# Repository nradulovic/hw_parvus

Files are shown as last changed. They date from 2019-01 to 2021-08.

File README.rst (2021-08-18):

.. contents:: Table of Contents
   :depth: 3

Introduction
============

This document shall describe rationales used to design and build audio
power amplifier using TDA7293 integrated circuit.

Architecture
============

The amplifier architecture consists of the following sections:

The amplifier consists of the following section:
 - Amplifier (AMP) board (left and right channels)
 - Input/output filtering and Interface (IOI) board
 - Power supply and control (PSC) board
 
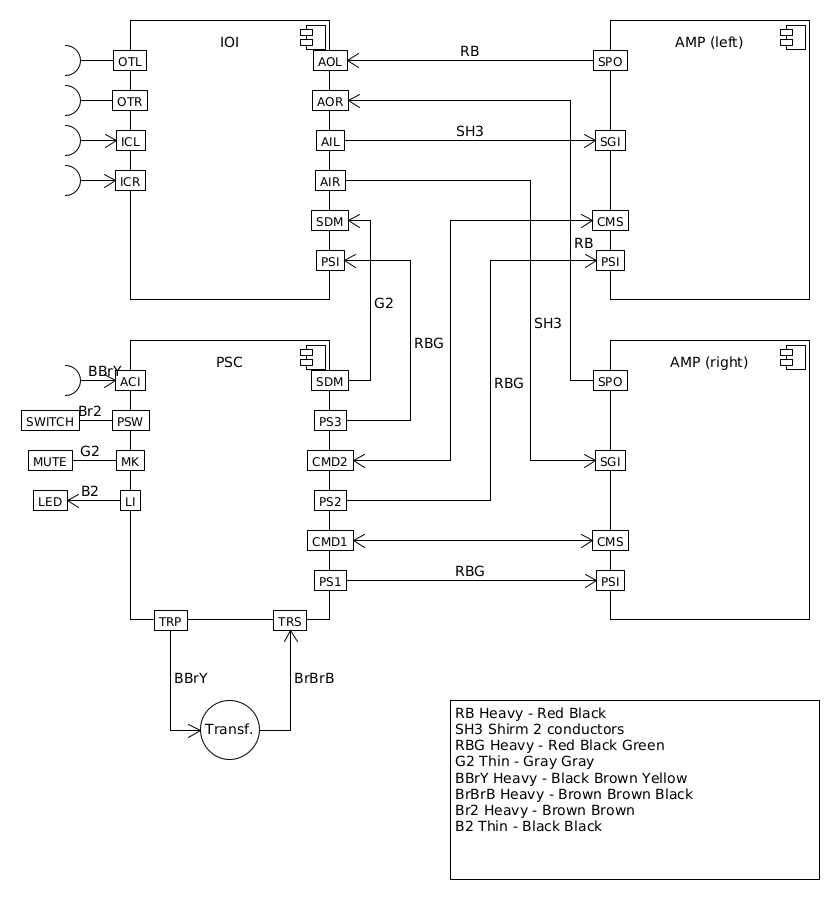
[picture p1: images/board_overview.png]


Each of these sections are implemented as a separate board.

Amplifier (AMP) board
=====================

Connections
-----------

The board features the following conntectors:

 - Power Supply Input - PSI: Vcc, GND, Vee
 - Speaker Output - SPO: Out, GND
 - Signal Input - SGI: In, SGND
 - Control and Mute Slave - CMS: Power sense, Mute, Clip, GND

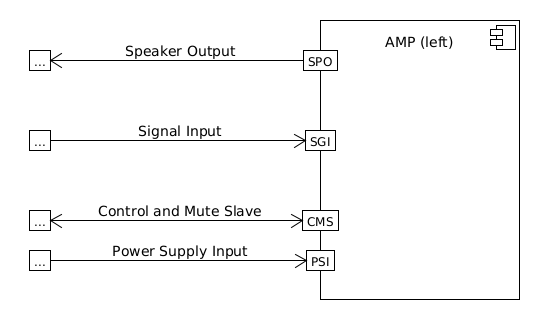
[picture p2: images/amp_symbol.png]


3D Render with components
-------------------------

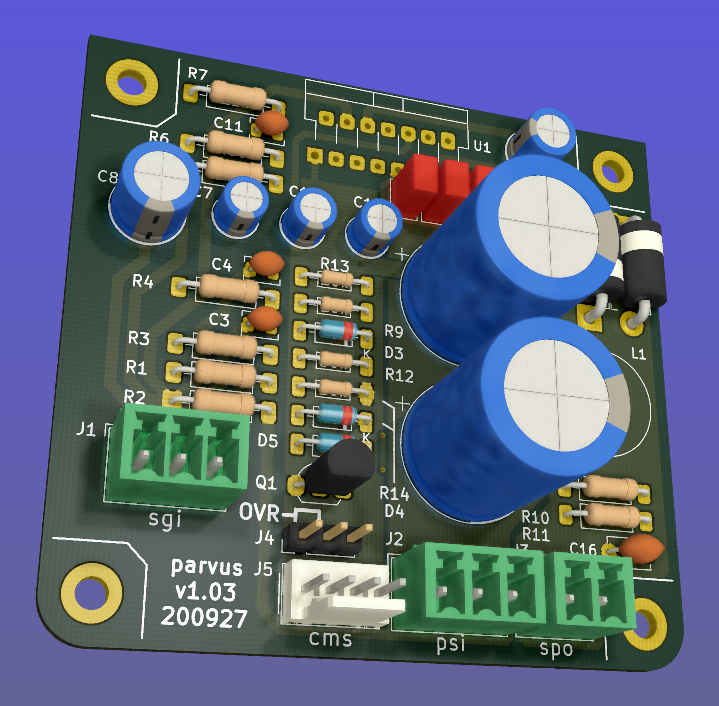
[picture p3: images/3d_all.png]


3D Render of board top layer
----------------------------

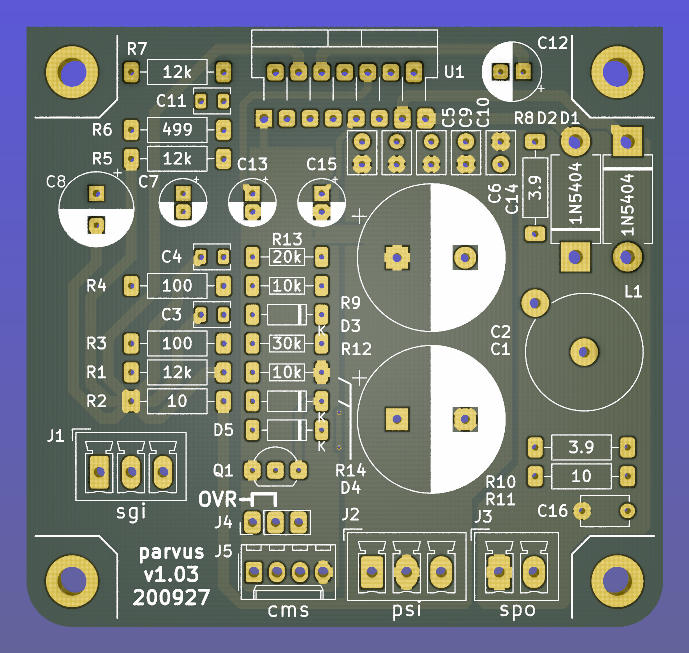
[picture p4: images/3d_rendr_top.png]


3D Render of board bottom layer
-------------------------------

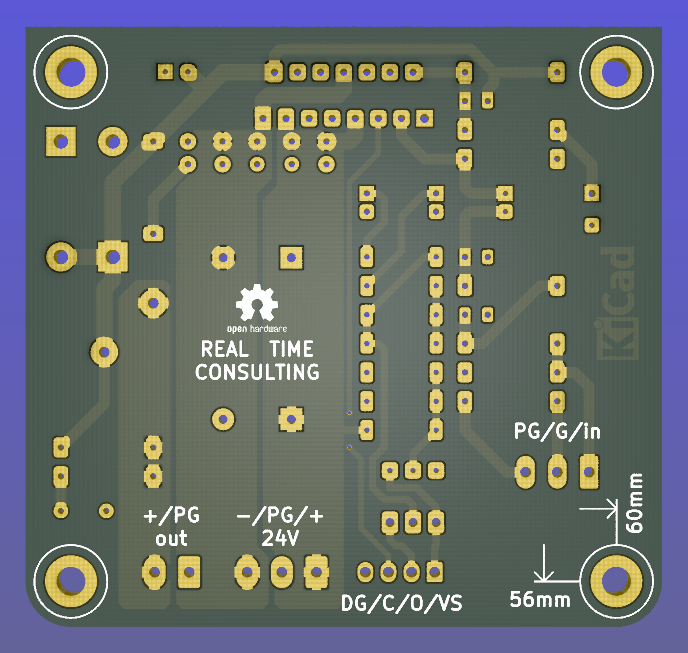
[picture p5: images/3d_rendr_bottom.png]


PCB Silkscreen plan
-------------------

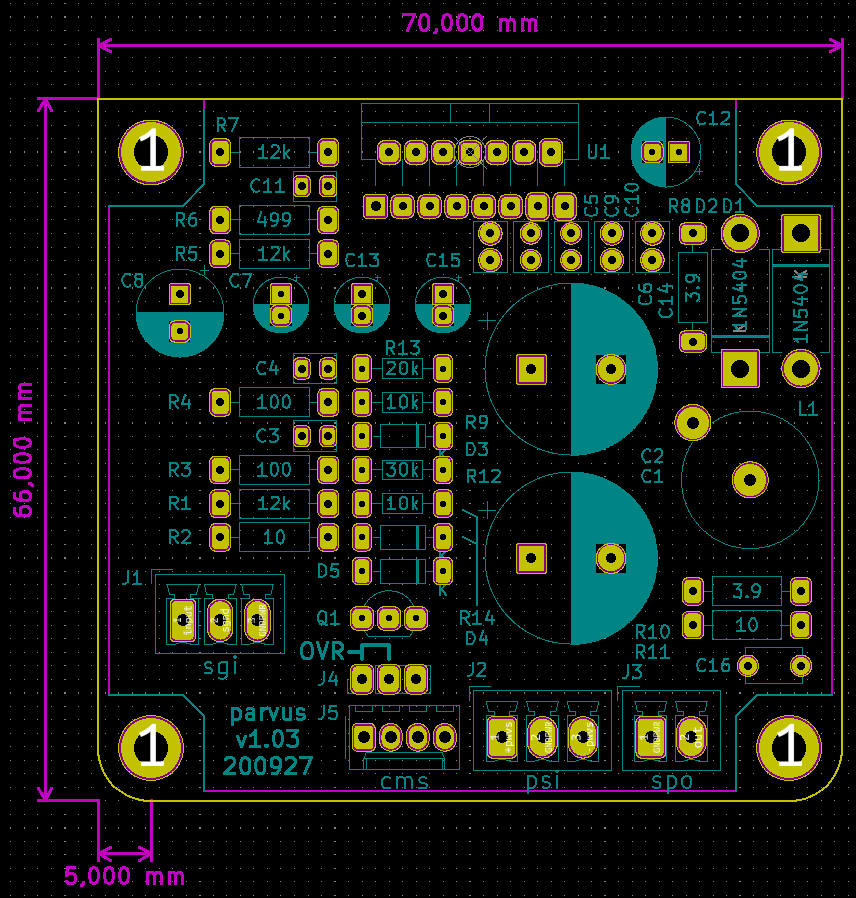
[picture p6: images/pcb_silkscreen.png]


Schematic
---------

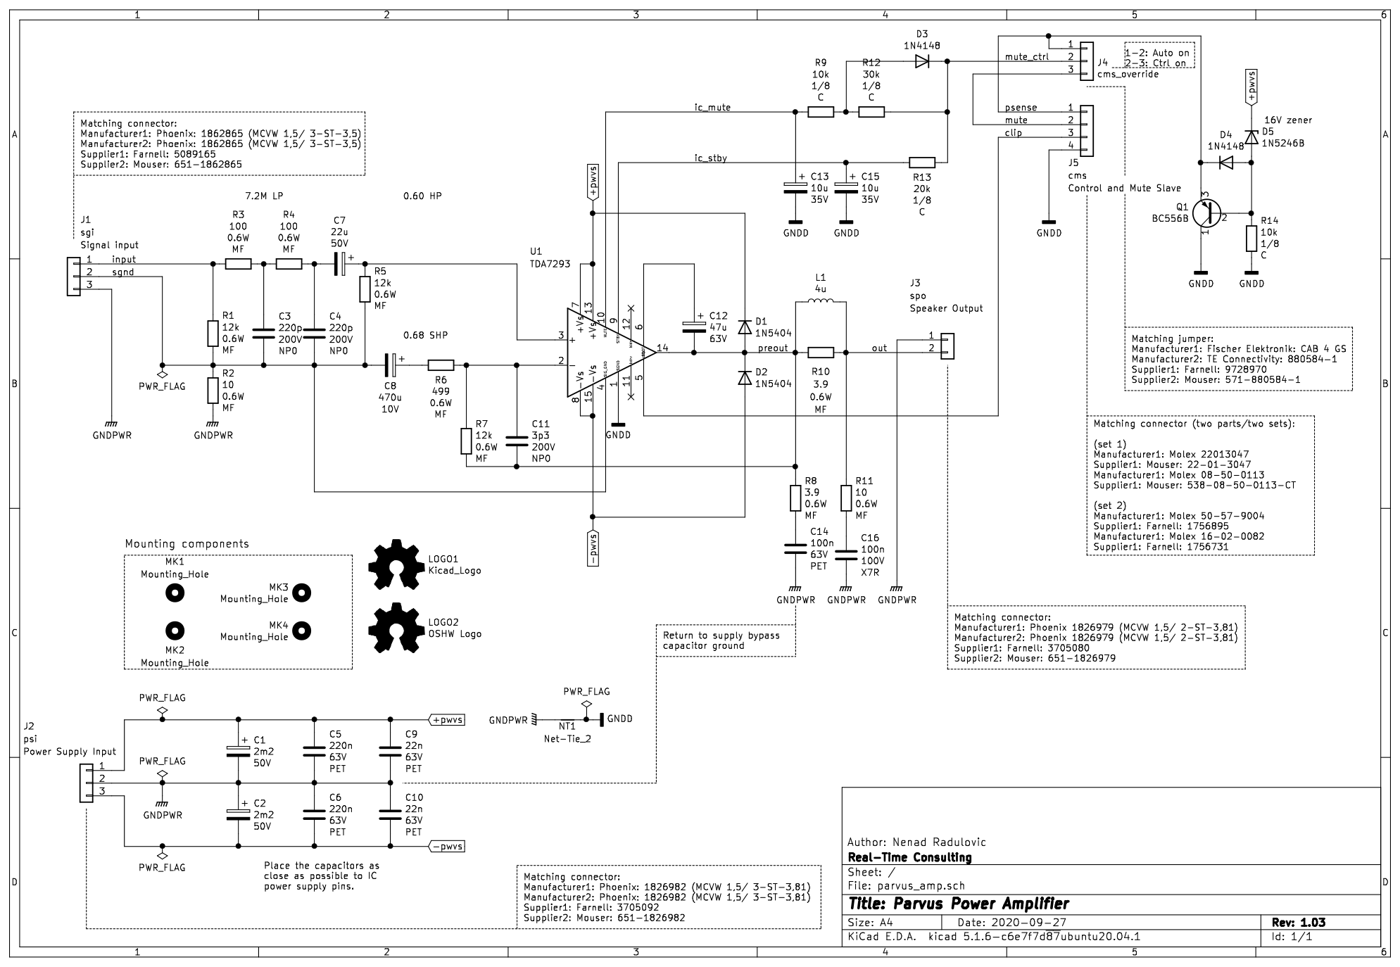
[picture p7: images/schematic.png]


Input low-pass filter
---------------------

For input filter we choose the frequency between 300kHz and 400kHz::

        +---+ Rlp1    +---+ Rlp2
    0---+   +----+----+   +---+---o Toward Amplifier IC block
        +---+    |    +---+   |
               ----- Clp1   ----- Clp2
               -----        -----
                 |            |
                === Ground   === Ground

Using the 2nd order CR low-pass filter calculator at URL:
*http://sim.okawa-denshi.jp/en/CRCRtool.php* we arrive at:

.. math::

    Rlp1 = 100 Ohm, Rlp2 = 100 Ohm

    Clp1 = 220pF,   Clp2 = 2.2nF

    fp1 = 352kHz

    fp2 = 14MHz

For more details please refer to: http://www.johnhearfield.com/RC/RC4.htm

The ground loop breaker resistor
--------------------------------

A ground loop breaker resistor is located between SGND and GNDPWR grounds. The
value of this resistor should be around 10 ohms.

Gain value
----------

Using inverted topology since we want to reduce common mode distortion in the
input stage. But in case of TDA7293 IC it is not easy to use inverted topology
since the mute circuit is implemented on positive OPAMP input.

The equivalent gain circuit resistance needs to stay below 600ohms. This is so
because all noise measurements in data-sheet were done with 600ohms or 0ohms.

Using low feedback gain is preferred for several reasons:
 * there is more loop gain available to reduce the distortion
 * reduced outout noues
 * lower offset at output

Nominal gain of an non-inverting amplifier is:

.. math::

    G=Rf/Rg+1

Since we have a voltage divider with same resistors in the front of the 
amplifier the total gain becomes:

.. math::

    G=Rf/Rg

The minimum gain specified in the TDA7293 datasheet is 26dB or 20 times. Just
to be on the safe side we choose 10% bigger value: 22

Chosen values for E24 series:
 * Rf = 12kOhm
 * Rg = 510 Ohm

Chosen values for E48 series:
 * Rf = 11kOhm
 * Rg = 499 Ohm

Frequency compensation
----------------------

The TDA7293 data-sheet does not provide enough of relevant data in order to
model the IC in AC domain. Since we can't model it there are no optimizations
available for the negative feedback circuit. But we can safely assume that
there are high frequency poles present in the TDA7293 transfer function. For
this reason we will add a few ``pF`` to calculated lead compensation
capacitor below (see ``Cadd``).

Lead compensation
^^^^^^^^^^^^^^^^^

Equivalent feedback network with lead compensation circuit::

          o Vout
          |
          *------+
          |      |
         +-+ Rf  |
         | |   ----- Cf=Cl (+Csi, see Input pin capacitance compensation)
         | |   -----
         +-+     |
   Vf     |      |
    o-----*------+
          |
         +-+ Rg
         | |
         | |
         +-+
          |
          o Input

Resistors `Rf` and `Rg` are part of feedback network. Capacitor `Cf` is the
compensation capacitor. The transfer function of this network is given as:

.. math::

    Vf(s)=I(s)*Rg

    Vout(s)=I(s)*(Rf||Cl + Rg)=I(s)*(Rf/(1+s*Rf*Cl)+Rg)

    H(s)=Vf(s)/Vout(s)=(Rg/(Rf+Rg))*((1+s*Rf*Cl)/(1+s*Re*Cl))

Zero:

.. math::

    wz=1/(Rf*Cl)

Pole:

.. math::

    wp=1/(Re*Cl)

Where:

.. math::

    Re=Rf||Rg=Rf*Rg/(Rf+Rg)

Rough estimation is to put additional 1-3pF in parallel to ``Rf``.

.. math::

	Cadd = 3pF

Input pin capacitance compensation
``````````````````````````````````

Input pins have the following parasitic capacitances associated:

* Cdiff
* Cm
* Cstray

The TDA7293 data-sheet does not specify any parameter regarding parasitic
input capacitances. Voltage feedback OPAMPS usually have both differential and
common-mode input impedances specified. In the absence of any information, it
is safe to use the model given in the next figure::

                   +----+ Zdiff
    +input o---+---|    |---+---o -input
               |   +----+   |
               |            |
              +-+ Zcm1     +-+ Zcm2
              | |          | |
              | |          | |
              +-+          +-+
               |            |
              ===          ===

We can use a rough estimation of values based on experience on using other 
audio FET OPAMPS, and typical values are around ``Cdiff=5pF``, ``Cm=4pF`` 
and ``Cstray=3pF``. All three equivalent capacitors are tied in parallel, 
so the total input capacitance becomes:

.. math::

    Cinput = Cdiff+Cm+Cstray=5pF+4pF+3pF=12pF

To mitigate this capacitance we can add capacitance `Csi` parallel to `Rf`
resistor. To compensate for this the following equation is applied:

.. math::

    Rf*Cf=Rg*Cinput

    Csi=Cinput*Rg/Rf=0.5pF

The final ``Cf`` value is:

.. math::

    Cf=Cl+Csi+Cadd=0+2+0.5=2.5pF

Any NP0 based capacitor around ``3pF`` will be good for this purpose.

Input/output filtering and Interface (IOI) board
================================================

Input circuit
-------------

Input EMI suppression
^^^^^^^^^^^^^^^^^^^^^

To protect the input from EMI we will use the following Zobel network::

          o Positive input or negative input
          |
          |
        ----- Czi
        -----
          |
          |
         +-+  Rzi
         | |
         | |
         +-+
          |
         === Ground

For most input cables characteristic impedance falls in range between
50 and 100ohm impedance and we are using the 75ohm as the middle value. The
resistor Rzi is ``Rzi=75ohm`` and the capacitor Czi is ``Czi=220pF``.
This network should be placed right at the input connector, not on the
main amplifier PCB.

Also, a 100n X7R capacitor shall be placed between SGND and chassis right at the
input connector. This capacitor will shunt radio and other interfirence signal
into the Chassis Ground potential.

Output circuit
--------------

Output EMI suppression
^^^^^^^^^^^^^^^^^^^^^^

Output network consists of upstream and downstream Zobel Network and of output
coil (``Ld``) with parallel, damping resistor (``Rd``). Upstream Zobel network 
provides a low-inductance load for the output stage at very high frequencies 
and allows high-frequency currents to circulate local to the output stage. The 
downstream Zobel network provides a good resistive termination right at the 
speaker terminals at high frequencies, helping to reduce RFI ingress and damp
resonances with, or reflections from, the speaker cables.
The output circuit is the following::

             Ld
             xxx
        +---x   x   x---+
        |        xxx    |
        |               |
        |   +-------+   |
    o---+---|       |---+---o
    Vout    +-------+   |   Vspeaker
        Rd              |
                      ----- Cz2 = 100nF
                      -----
                        |
                        |
                       +-+  Rz1 = 10 Ohm
                       | |
                       | |
                       +-+
                        |
                       ===

The output coil ``Ld`` provides high frequency isolation of output load from 
output stage in TDA7293. The inductance value should be between 2uH up to 5uH.
Output shunt resistor should be between 2 and 5 Ohms. See
*Douglas Self - Audio Power Amplifier Design Handbook, 3rd Ed., Output networks, chapter 7*
for effect on power amplifier transfer function.

Power supply
============

Power amplifier power supply
----------------------------

The power supply section is using single bank of 10mF capacitors.

We are using dual symmetrical supplies from since dual secondaries.

The main voltage supplies are supplied directly from reservoir capacitors. This
supply powers the high current, high power output sections of TDA7293.

Before rectifier diodes a snubber RC circuit should be placed to decrease diode
switching impulse. Recommended values are ``Rsn = 1 Ohm``, ``Csn = 470nF``::

          o Vsupply
          |
          |
        ----- Csn = 470nF
        -----
          |
          |
         +-+  Rsn = 1 Ohm
         | |
         | |
         +-+
          |
         === Ground

This snubber may be placed near the IC power supply lines, too.

AC mains
--------

NOTE:
 * On case chassis there should be a safety ground screw just near at the input
   220V socket.

Chassis
=======

Component height
----------------

Power supply capacitors on amplifier boards:

* 30mm (10mF)

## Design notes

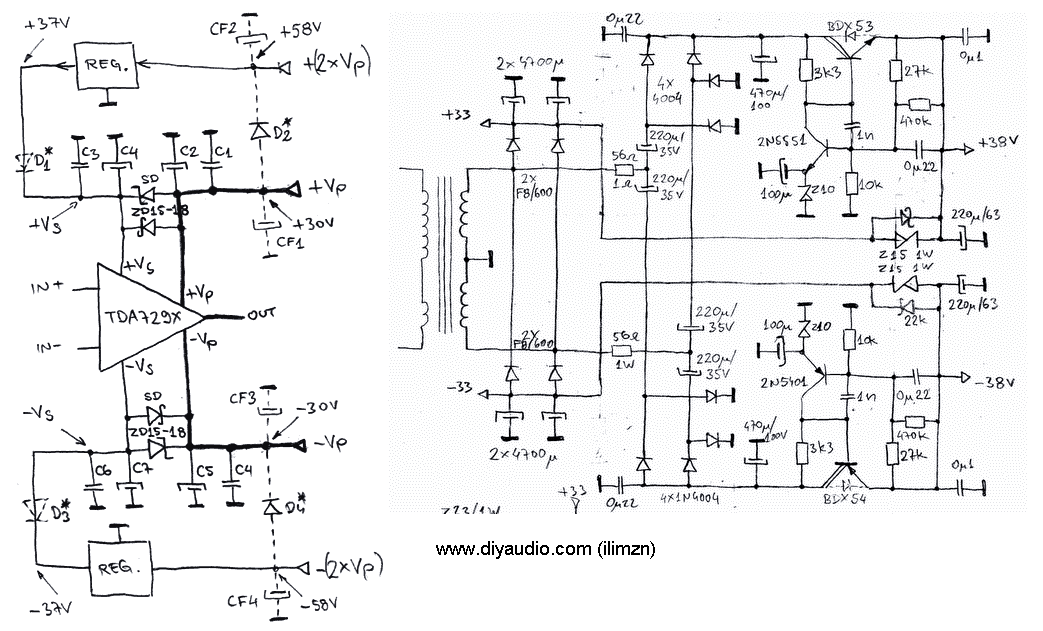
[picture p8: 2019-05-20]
docs/TDA7294_ilimzn.PNG

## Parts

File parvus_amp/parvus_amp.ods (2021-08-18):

Reference | Quantity | Value | Footprint | Datasheet | Manufacturer1 | Manufacturer2 | Supplier1 | Supplier2 | Type | Voltage | Power
C1 C2 | 2 | 2m2 | Capacitor_THT:CP_Radial_D16.0mm_P7.50mm | http://www.farnell.com/datasheets/2321616.pdf | Rybicon: 50YXJ2200M16X35.5 | Nichicon: UPW1V222MHD | Farnell: 2346272 | Mouser: 647-UPW1V222MHD |  | 50V
C11 | 1 | 3p3 | Capacitor_THT:C_Disc_D3.8mm_W2.6mm_P2.50mm | http://www.farnell.com/datasheets/2577345.pdf | Kemet: C315C339D2G5TA | Kemet: C315C339D2G5TA | Farnell: 2819636 | Mouser: 80-C315C339D2G | NP0 | 200V
C12 | 1 | 47u | Capacitor_THT:CP_Radial_D6.3mm_P2.50mm | http://www.farnell.com/datasheets/2321616.pdf | Rybicon: 63YXJ47M6.3X11 | Nichicon: UPW1H470MED | Farnell: 2346274 | Mouser: 647-UPW1H470MED |  | 63V
C13 C15 | 2 | 10u | Capacitor_THT:CP_Radial_D5.0mm_P2.00mm | http://www.farnell.com/datasheets/1723232.pdf | Multicomp: MCGPR35V106M5X11 | Nichicon: UVZ1V100MDD1TD | Farnell: 9451242 | Mouser: 647-UVZ1V100MDD1TD |  | 35V
C14 | 1 | 100n | Capacitor_THT:C_Rect_L4.6mm_W3.0mm_P2.50mm_MKS02_FKP02 | http://www.farnell.com/datasheets/1306005.pdf | WIMA: MKS0C031000C00KSSD | WIMA: MKS0C031000C00KSSD | Farnell: 1006004 | Mouser: 505-MKS02.1/63/10 | PET | 63V
C16 | 1 | 100n | Capacitor_THT:C_Disc_D5.1mm_W3.2mm_P5.00mm | http://www.farnell.com/datasheets/2095938.pdf | AVX: SR211C104KAR | AVX: SR211C104KAR | Farnell: 1100408 | Mouser: 581-SR211C104KAR | X7R | 100V
C3 C4 | 2 | 220p | Capacitor_THT:C_Disc_D3.8mm_W2.6mm_P2.50mm | http://www.farnell.com/datasheets/2577335.pdf | Kemet: C315C221K2G5TA | Kemet: C315C221K2G5TA | Farnell: 2819626 | Mouser: 80-C315C221K2G | NP0 | 200V
C5 C6 | 2 | 220n | Capacitor_THT:C_Rect_L4.6mm_W3.0mm_P2.50mm_MKS02_FKP02 | http://www.farnell.com/datasheets/1306005.pdf | WIMA: MKS0C032200C00KSSD | WIMA: MKS0C032200C00KSSD | Farnell: 1890123 | Mouser: 505-MKS0C032200C00KS | PET | 63V
C7 | 1 | 22u | Capacitor_THT:CP_Radial_D5.0mm_P2.00mm | http://www.farnell.com/datasheets/2328501.pdf | Rybicon: 50YXJ22MTA5X11 | Nichicon: UPW2A22MDD | Farnell: 2346268 | Mouser: 647-UPW2A22MDD |  | 50V
C8 | 1 | 470u | Capacitor_THT:CP_Radial_D8.0mm_P3.50mm | http://www.farnell.com/datasheets/2321616.pdf | Rybicon:10YXJ470M6.3X11 | Nichicon: UPW0J471MPD | Farnell: 2346252 | Mouser: 647-UPW0J471MPD |  | 10V
C10 C9 | 2 | 22n | Capacitor_THT:C_Rect_L4.6mm_W3.0mm_P2.50mm_MKS02_FKP02 | http://www.farnell.com/datasheets/1306005.pdf | WIMA: MKS0C022200B00KSSD | WIMA: MKS0C022200B00KSSD | Farnell: 1006001 | Mouser: 505-MKS02.022/63/10 | PET | 63V
D1 D2 | 2 | 1N5404 | Diode_THT:D_DO-201AD_P12.70mm_Horizontal | http://www.onsemi.com/PowerSolutions/supportDoc.do?type=models&rpn=1N5404 | ON Semiconductor: 1N5404RL | ON Semiconductor: 1N5404RL | Farnell: 9556141 | Mouser: 863-1N5404RLG
D3 D4 | 2 | 1N4148 | Diode_THT:D_DO-35_SOD27_P7.62mm_Horizontal | https://www.onsemi.com/pub/Collateral/1N914A-D.pdf | ON Semiconductor: 1N4148 | ON Semiconductor: 1N4148 | Farnell: 2322485 | Mouser: 512-1N4148
D5 | 1 | 1N5246B | Diode_THT:D_DO-35_SOD27_P7.62mm_Horizontal | https://www.onsemi.com/pub/Collateral/1N5221B-D.PDF | ON Semiconductor: 1N5246BTR | ON Semiconductor: 1N5246BTR | Farnell: 2453748 | Mouser: 512-1N5246BTR
J1 | 1 | input | Connector_Phoenix_MC:PhoenixContact_MCV_1,5_3-G-3.5_1x03_P3.50mm_Vertical | http://www.farnell.com/datasheets/2309782.pdf | Phoenix: 1843619 (MCV 1,5/ 3-G-3,50) | Phoenix: 1843619 (MCV 1,5/ 3-G-3,50) | Farnell: 3704828 | Mouser: 651-1843619
J2 | 1 | power | Connector_Phoenix_MC:PhoenixContact_MCV_1,5_3-G-3.81_1x03_P3.81mm_Vertical | http://www.farnell.com/datasheets/2138271.pdf | Phoenix: 1803439 (MCV 1,5/ 3-G-3,81) | Phoenix: 1803439 (MCV 1,5/ 3-G-3,81) | Farnell: 3913089 | Mouser: 651-1803439
J3 | 1 | output | Connector_Phoenix_MC:PhoenixContact_MCV_1,5_2-G-3.81_1x02_P3.81mm_Vertical | http://www.farnell.com/datasheets/2133308.pdf | Phoenix: 1803426 (MCV 1,5/ 2-G-3,81) | Phoenix: 1803426 (MCV 1,5/ 2-G-3,81) | Farnell: 3913077 | Mouser: 651-1803426
J4 | 1 | ctrl_override | Connector_PinHeader_2.54mm:PinHeader_1x03_P2.54mm_Vertical | https://www.molex.com/webdocs/datasheets/pdf/en-us/0022284031_PCB_HEADERS.pdf | Molex: 22-28-4031 | Molex: 22-28-4031 | Farnell: 3049527 | Mouser: 538-22-28-4031
J5 | 1 | ctrl | Connector_Molex:Molex_KK-254_AE-6410-04A_1x04_P2.54mm_Vertical | http://www.farnell.com/datasheets/2697192.pdf | Molex: 171856-0004 |  | Mouser: 538-171856-0004
Q1 | 1 | BC556B | Package_TO_SOT_THT:TO-92L_Inline_Wide | https://www.onsemi.com/pub/Collateral/BC556B-D.PDF | ON Semiconductor: BC556BTA | ON Semiconductor: BC556BTA | Farnell: 2985373 | Mouser: 512-BC556BTA
R11 R2 | 2 | 10 | Resistor_THT:R_Axial_DIN0207_L6.3mm_D2.5mm_P10.16mm_Horizontal | http://www.farnell.com/datasheets/1723855.pdf | TE Connectivity: LR1F10R | TE Connectivity: LR1F10R | Farnell: 2329993 | Mouser: 279-LR1F10R | MF |  | 0.6W
R12 | 1 | 30k | Resistor_THT:R_Axial_DIN0204_L3.6mm_D1.6mm_P7.62mm_Horizontal | http://www.farnell.com/datasheets/1716726.pdf | Multicomp: MF12 30K | Yageo: CFR-12JB-52-30K | Farnell: 9343008 | Mouser: 603-CFR-12JB-52-30K | C |  | 1/8
R13 | 1 | 20k | Resistor_THT:R_Axial_DIN0204_L3.6mm_D1.6mm_P7.62mm_Horizontal | http://www.farnell.com/datasheets/1716726.pdf | Multicomp: MF12 20K | Yageo: CFR-12JB-52-20K | Farnell: 9342796 | Mouser: 603-CFR-12JB-52-20K | C |  | 1/8
R3 R4 | 2 | 100 | Resistor_THT:R_Axial_DIN0207_L6.3mm_D2.5mm_P10.16mm_Horizontal | http://www.farnell.com/datasheets/1723855.pdf | TE Connectivity: LR1F100R | TE Connectivity: LR1F100R | Farnell: 2329988 | Mouser: 279-LR1F100R | MF |  | 0.6W
R1 R5 R7 | 3 | 12k | Resistor_THT:R_Axial_DIN0207_L6.3mm_D2.5mm_P10.16mm_Horizontal | http://www.farnell.com/datasheets/1723855.pdf | TE Connectivity: LR1F12K | TE Connectivity: LR1F12K | Farnell: 2330007 | Mouser: 279-LR1F12K | MF |  | 0.6W
R6 | 1 | 499 | Resistor_THT:R_Axial_DIN0207_L6.3mm_D2.5mm_P10.16mm_Horizontal | http://www.farnell.com/datasheets/1723855.pdf | TE Connectivity: LR1F499R | TE Connectivity: LR1F499R | Farnell: 2330163 | Mouser: 279-LR1F499R | MF |  | 0.6W
R10 R8 | 2 | 3.9 | Resistor_THT:R_Axial_DIN0207_L6.3mm_D2.5mm_P10.16mm_Horizontal | http://www.farnell.com/datasheets/1723855.pdf | TE Connectivity: LR1F3R9 | Vishay/BC Components: PR01000103908JR500 | Farnell: 2330141 | Mouser: 594-5073NW3R900J | MF |  | 0.6W
R14 R9 | 2 | 10k | Resistor_THT:R_Axial_DIN0204_L3.6mm_D1.6mm_P7.62mm_Horizontal | http://www.farnell.com/datasheets/1716726.pdf | Multicomp: MF12 10K | Yageo: CFR-12JB-52-10K | Farnell: 9342419 | Mouser: 603-CFR-12JB-52-10K | C |  | 1/8
U1 | 1 | TDA7293 | Package_TO_SOT_THT:TO-220-15_P2.54x2.54mm_StaggerOdd_Lead4.58mm_Vertical | http://www.farnell.com/datasheets/1761334.pdf | ST:TDA7293V | ST:TDA7293V | Farnell: 1366582 | Mouser: 511-TDA7293V

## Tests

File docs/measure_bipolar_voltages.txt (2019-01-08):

Here is a complete procedure for finding the three required resistor values to get the
range exactly from 0 to 5v (0 to Vref) with the center at 2.5v to the AD input.

The three resistor network is made by connecting a resistor (Ru)
from Vref to ADin, another resistor (Rd) from ADin to ground (0v),
and the input resistor (Rin) from the ADin to your voltage to
be measured (Vin).
By using this network, the AD input will be presented with a voltage (Vou)
which goes highest for the highest input (Vu) and lowest (Vod) for the
lowest input (Vd).

If we assume Vout for 0v input is Vref/2 then the following
simplifications result...

A=(Vu-Vd)/(2*(Vou-Vod))-1
Rin=Rd*A
Ru=Rin/(A+1)

where
Vu is the highest input voltage (+10v in your app)
Vd is the lowest input voltage (-10v in your app)
Vou is the highest output voltage presented to the AD input (max possible is Vref)
Vod is the lowest output voltage presented to the AD input (min possible is 0v)

DESIGN EXAMPLE

Your app must take an input voltage that ranges from -10v to +10v,
and you are using a Vref of +5 volts.  You want to use the full range
of the AD converter so you use Vou=+5 and Vod=0 .
Because your app input ranges from -10v to +10v that makes Vd=-10
and Vu=+10.
The input to the AD converter must be sourced from an input resistance
of 10k or less (we are using 10k as the example here, but lower this
for other chips that require less input resistance).  This means we
can guess the value of Rd to be equal to 20k (twice the value of 10k).

Now we have all the information required to calculate the other two
resistors, but to recap:

Vu=10
Vd=-10
Vou=5
Vod=0
Rd=20 (working all resistors in K ohms)

First calculate A:

A=(Vu-Vd)/(2*(Vou-Vod))-1=1

Next calculate Rin:

Rin=Rd*A=20

Finally, calculate Ru:

Ru=Rin/(A+1)=10

Thus, with Rd=20k the other two resistors come out to be:

Rin=20k
Ru=10k

and we have all the required resistor values.

At this point we can check the input resistance for this network:
RAD=1/(1/Rin+1/Ru+1/Rd)

and adjust the three resistors if necessary.  Doing this
helps us get the highest possible input resistance when needed.
To adjust this we first calculate RAD with the resistors we found
so far:
Rd=20
Rin=20
Ru=10
RAD=1/(1/Rin+1/Ru+1/Rd)=5

then calculate a K factor to multiply all the resistors by:
Rz=10 (this is the max AD input resistance for the chip)
K=Rz*(1/(Rin)+1/(Ru)+1/(Rd))=2

so for this app K=2.  Now we multiply all the previous resistor
values by this K to get the final value for each:
Rd=Rd*K=40
Rin=Rin*K=40
Ru=Ru*K=20

so the final values for all the resistors are:
Rd=40
Rin=40
Ru=20

We dont have to include that step, but it assures that we are using
the maximum input impedance possible for our signal to be measured.

A quick check can be done with the following equations for the input
to the AD converter (Vout here):

Rui=Ru*Rin/(Ru+Rin)
Rdi=Rd*Rin/(Rd+Rin)
Rud=Ru*Rd/(Ru+Rd)
v1=Vref*Rdi/(Rdi+Ru)
v2=Vin*Rud/(Rud+Rin)
Vout=v1+v2

Using the values we found for the three resistors
Rd=40
Rin=40
Ru=20

and the input voltage values:
Vu=10
Vd=-10

and a reference voltage of 5 volts:
Vref=5

we first calculate three constant resistances that simplify the
other calculations:

Rui=Ru*Rin/(Ru+Rin)=13.333333
Rdi=Rd*Rin/(Rd+Rin)=20
Rud=Ru*Rd/(Ru+Rd)=13.333333

now with Vin equal to the highest input voltage we calculate the
upper voltage that will be presented to the AD input:
Vin=Vu=10
v1=Vref*Rdi/(Rdi+Ru)=2.5
v2=Vin*Rud/(Rud+Rin)=2.5
Vout=v1+v2=5

so this calculation checks out ok.

Next we calculate the lowest voltage that will get to the AD input
by setting Vin equal to -10 volts:
Vin=Vd=-10
v1=Vref*Rdi/(Rdi+Ru)=2.5
v2=Vin*Rud/(Rud+Rin)=-2.5
Vout=v1+v2=0

so the lower input calculation also checks out ok.

Next we can verify that for zero volts input we get one half
the reference voltage (one half of 5v is 2.5v):

Vin=0
v1=Vref*Rdi/(Rdi+Ru)=2.5
v2=Vin*Rud/(Rud+Rin)=0
Vout=v1+v2=2.5

This also checks out so we know that for an input of -10v to +10v
we will get a 0v to 5v AD signal, and it will be centered at 2.5v
for a 0v input.

Note that after doing the calculations for the three resistors it is a good
idea to also do the voltage checks, as if there is an error in even one of
the resistors the chip could get blown out.

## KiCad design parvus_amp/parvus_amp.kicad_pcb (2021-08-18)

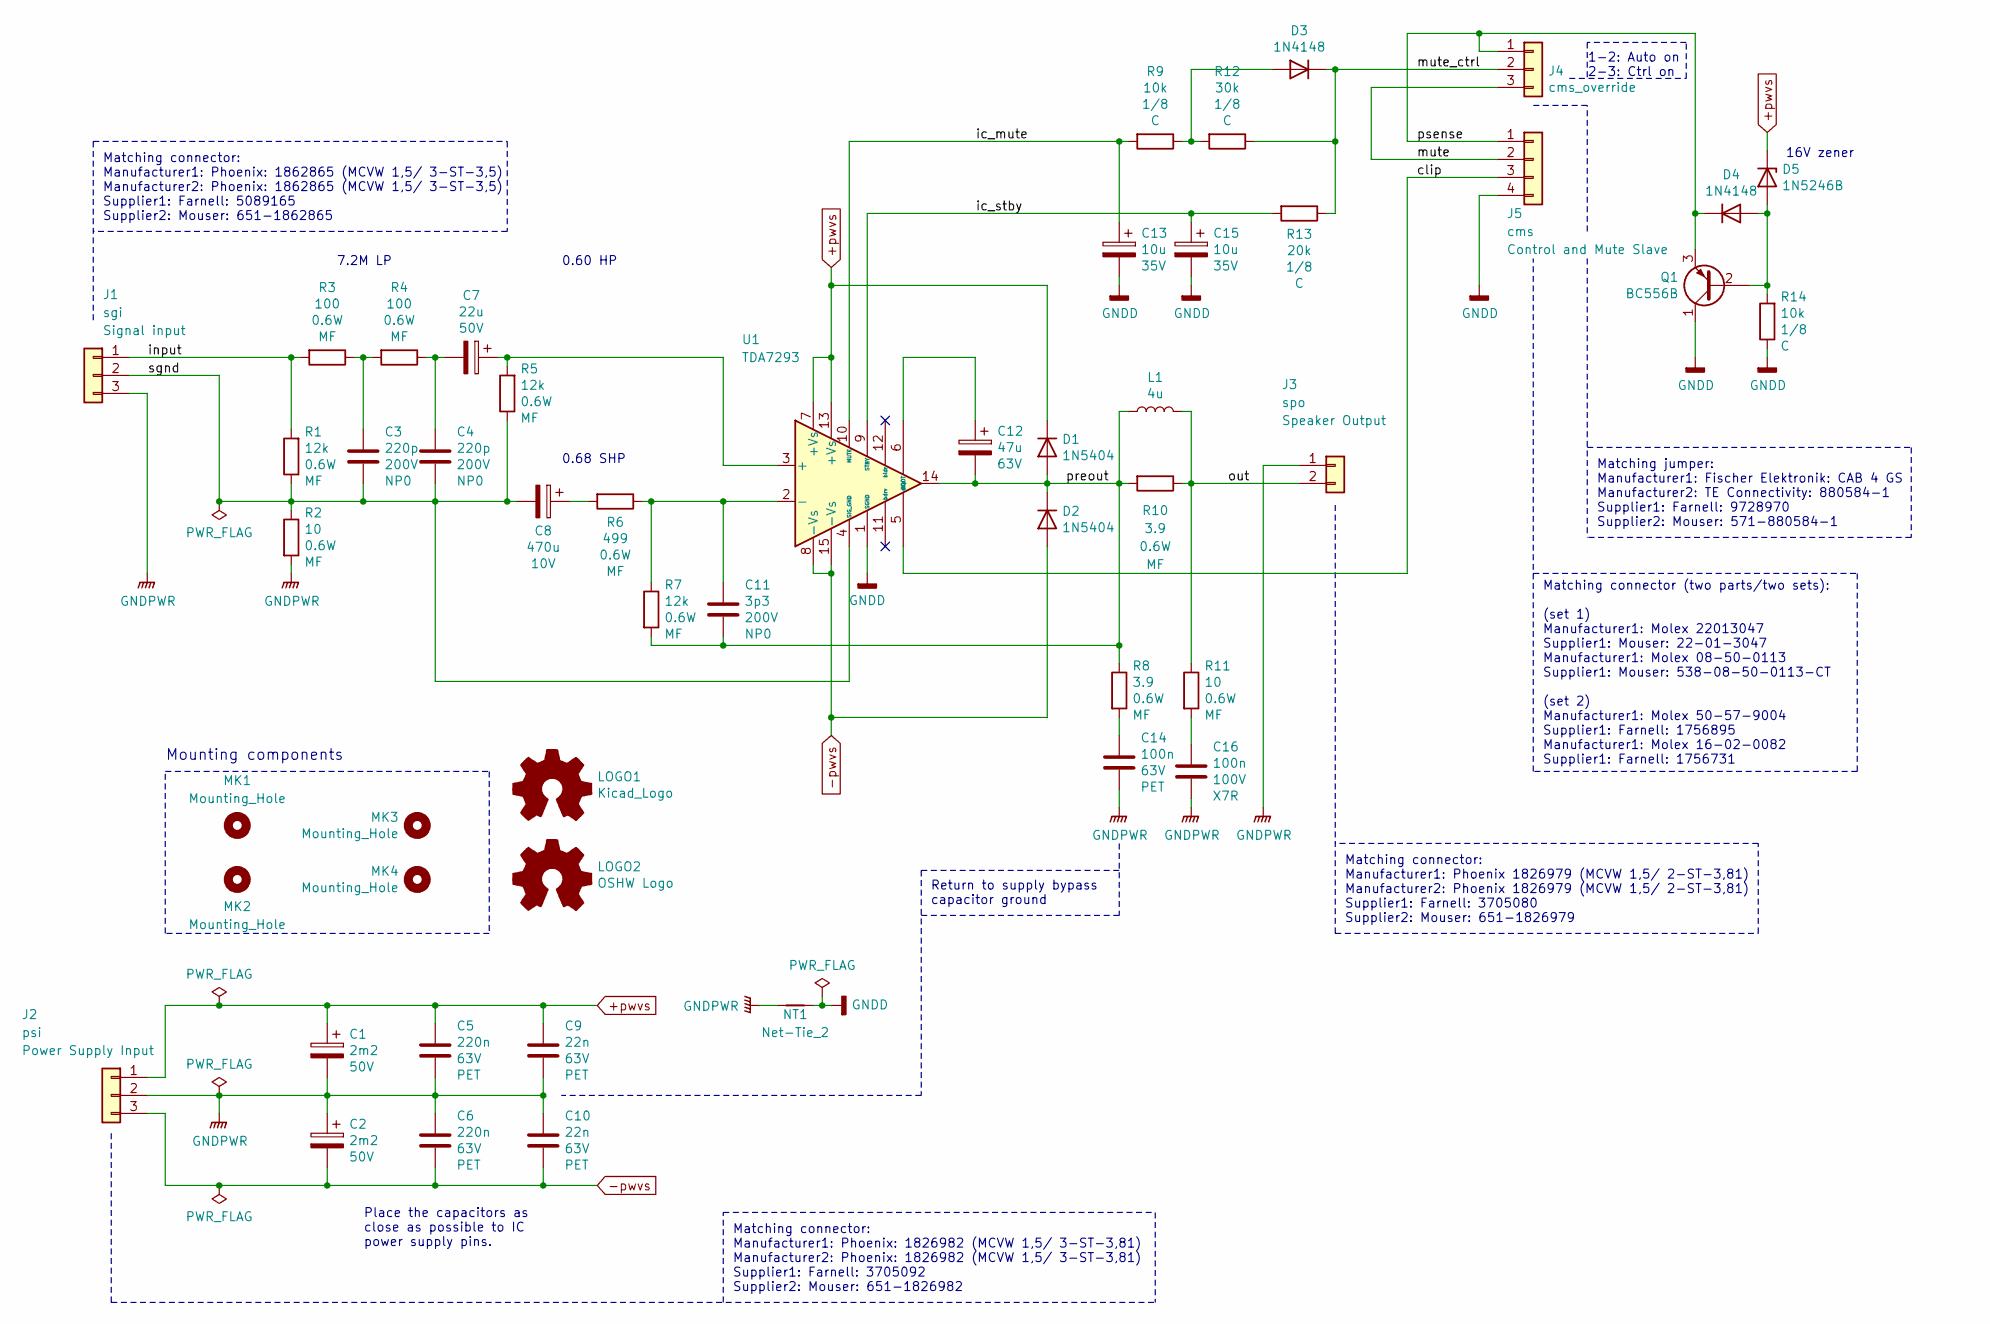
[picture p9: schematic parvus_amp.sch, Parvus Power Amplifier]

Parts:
C1, C2: 2m2; CP_Radial_D16.0mm_P7.50mm; Voltage 50V
C3, C4: 220p; C_Disc_D3.8mm_W2.6mm_P2.50mm; Voltage 200V
C5, C6: 220n; C_Rect_L4.6mm_W3.0mm_P2.50mm_MKS02_FKP02; Voltage 63V
C7: 22u; CP_Radial_D5.0mm_P2.00mm; Voltage 50V
C8: 470u; CP_Radial_D8.0mm_P3.50mm; Voltage 10V
C9, C10: 22n; C_Rect_L4.6mm_W3.0mm_P2.50mm_MKS02_FKP02; Voltage 63V
C11: 3p3; C_Disc_D3.8mm_W2.6mm_P2.50mm; Voltage 200V
C12: 47u; CP_Radial_D6.3mm_P2.50mm; Voltage 63V
C13, C15: 10u; CP_Radial_D5.0mm_P2.00mm; Voltage 35V
C14: 100n; C_Rect_L4.6mm_W3.0mm_P2.50mm_MKS02_FKP02; Voltage 63V
C16: 100n; C_Disc_D5.1mm_W3.2mm_P5.00mm; Voltage 100V
D1, D2: 1N5404; D_DO-201AD_P12.70mm_Horizontal
D3, D4: 1N4148; D_DO-35_SOD27_P7.62mm_Horizontal
D5: 1N5246B; D_DO-35_SOD27_P7.62mm_Horizontal
J1: sgi; PhoenixContact_MCV_1,5_3-G-3.5_1x03_P3.50mm_Vertical
J2: psi; PhoenixContact_MCV_1,5_3-G-3.81_1x03_P3.81mm_Vertical
J3: spo; PhoenixContact_MCV_1,5_2-G-3.81_1x02_P3.81mm_Vertical
J4: cms_override; PinHeader_1x03_P2.54mm_Vertical
J5: cms; Molex_KK-254_AE-6410-04A_1x04_P2.54mm_Vertical
L1: 4u; L_Axial_L20.3mm_D12.7mm_P7.62mm_Vertical_Vishay_IHA-201
LOGO1: Kicad_Logo; KiCad-Logo_5mm_Copper
LOGO2: OSHW Logo; OSHW-Logo2_7.3x6mm_SilkScreen
MK1, MK2, MK3, MK4: Mounting_Hole; MountingHole_3.2mm_M3_ISO7380_Pad
NT1: Net-Tie_2; NetTie-2_SMD_Pad2.0mm
Q1: BC556B; TO-92L_Inline_Wide
R1, R5, R7: 12k; R_Axial_DIN0207_L6.3mm_D2.5mm_P10.16mm_Horizontal
R2, R11: 10; R_Axial_DIN0207_L6.3mm_D2.5mm_P10.16mm_Horizontal
R3, R4: 100; R_Axial_DIN0207_L6.3mm_D2.5mm_P10.16mm_Horizontal
R6: 499; R_Axial_DIN0207_L6.3mm_D2.5mm_P10.16mm_Horizontal
R8, R10: 3.9; R_Axial_DIN0207_L6.3mm_D2.5mm_P10.16mm_Horizontal
R9, R14: 10k; R_Axial_DIN0204_L3.6mm_D1.6mm_P7.62mm_Horizontal
R12: 30k; R_Axial_DIN0204_L3.6mm_D1.6mm_P7.62mm_Horizontal
R13: 20k; R_Axial_DIN0204_L3.6mm_D1.6mm_P7.62mm_Horizontal
U1: TDA7293; TO-220-15_P2.54x2.54mm_StaggerOdd_Lead4.58mm_Vertical

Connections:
+pwvs: C1.1, C5.1, C9.1, D1.1 (K), D5.1 (K), J2.1, U1.7 (+Vs), U1.13 (+Vs)
-pwvs: C2.2, C6.2, C10.2, D2.2 (A), J2.3, U1.8 (-Vs), U1.15 (-Vs)
/clip: J5.3, U1.5 (clip)
/ic_mute: C13.1, R9.2, U1.10 (MUTE)
/ic_stby: C15.1, R13.2, U1.9 (STBY)
/input: J1.1, R1.2, R3.2
/mute: J4.3, J5.2
/mute_ctrl: D3.1 (K), J4.2, R12.1, R13.1
/out: J3.2, L1.2, R10.1, R11.1
/preout: C11.2, C12.2, D1.2 (A), D2.1 (K), L1.1, R7.2, R8.1, R10.2, U1.14
/psense: D4.1 (K), J4.1, J5.1, Q1.3 (E)
/sgnd: C3.2, C4.2, C8.2, J1.2, R1.1, R2.1, R5.1, U1.4 (SIG_GND)
GNDD: C13.2, C15.2, J5.4, NT1.2, Q1.1 (C), R14.1, U1.1 (SGND)
GNDPWR: C1.2, C2.1, C5.2, C6.1, C9.2, C10.1, C14.2, C16.2, J1.3, J2.2, J3.1, NT1.1, R2.2
unnamed: C3.1, R3.1, R4.2
unnamed: C4.1, C7.2, R4.1
unnamed: C7.1, R5.2, U1.3 (+)
unnamed: C8.1, R6.2
unnamed: C11.1, R6.1, R7.1, U1.2 (-)
unnamed: C12.1, U1.6 (BOOT)
unnamed: C14.1, R8.2
unnamed: C16.1, R11.2
unnamed: D3.2 (A), R9.1, R12.2
unnamed: D4.2 (A), D5.2 (A), Q1.2 (B), R14.2

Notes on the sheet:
Mounting components
0.68 SHP
0.60 HP
Return to supply bypass capacitor ground
Place the capacitors as close as possible to IC power supply pins.
7.2M LP
Matching connector (two parts/two sets): (set 1) Manufacturer1: Molex 22013047 Supplier1: Mouser: 22-01-3047 Manufacturer1: Molex 08-50-0113 Supplier1: Mouser: 538-08-50-0113-CT (set 2) Manufacturer1: Molex 50-57-9004 Supplier1: Farnell: 1756895 Manufacturer1: Molex 16-02-0082 Supplier1: Farnell: 1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
Matching connector: Manufacturer1: Phoenix: 1862865 (MCVW 1,5/ 3-ST-3,5) Manufacturer2: Phoenix: 1862865 (MCVW 1,5/ 3-ST-3,5) Supplier1: Farnell: 5089165 Supplier2: Mouser: 651-1862865
Matching connector: Manufacturer1: Phoenix 1826979 (MCVW 1,5/ 2-ST-3,81) Manufacturer2: Phoenix 1826979 (MCVW 1,5/ 2-ST-3,81) Supplier1: Farnell: 3705080 Supplier2: Mouser: 651-1826979
Matching connector: Manufacturer1: Phoenix: 1826982 (MCVW 1,5/ 3-ST-3,81) Manufacturer2: Phoenix: 1826982 (MCVW 1,5/ 3-ST-3,81) Supplier1: Farnell: 3705092 Supplier2: Mouser: 651-1826982
Matching jumper: Manufacturer1: Fischer Elektronik: CAB 4 GS Manufacturer2: TE Connectivity: 880584-1 Supplier1: Farnell: 9728970 Supplier2: Mouser: 571-880584-1
16V zener
1-2: Auto on 2-3: Ctrl on

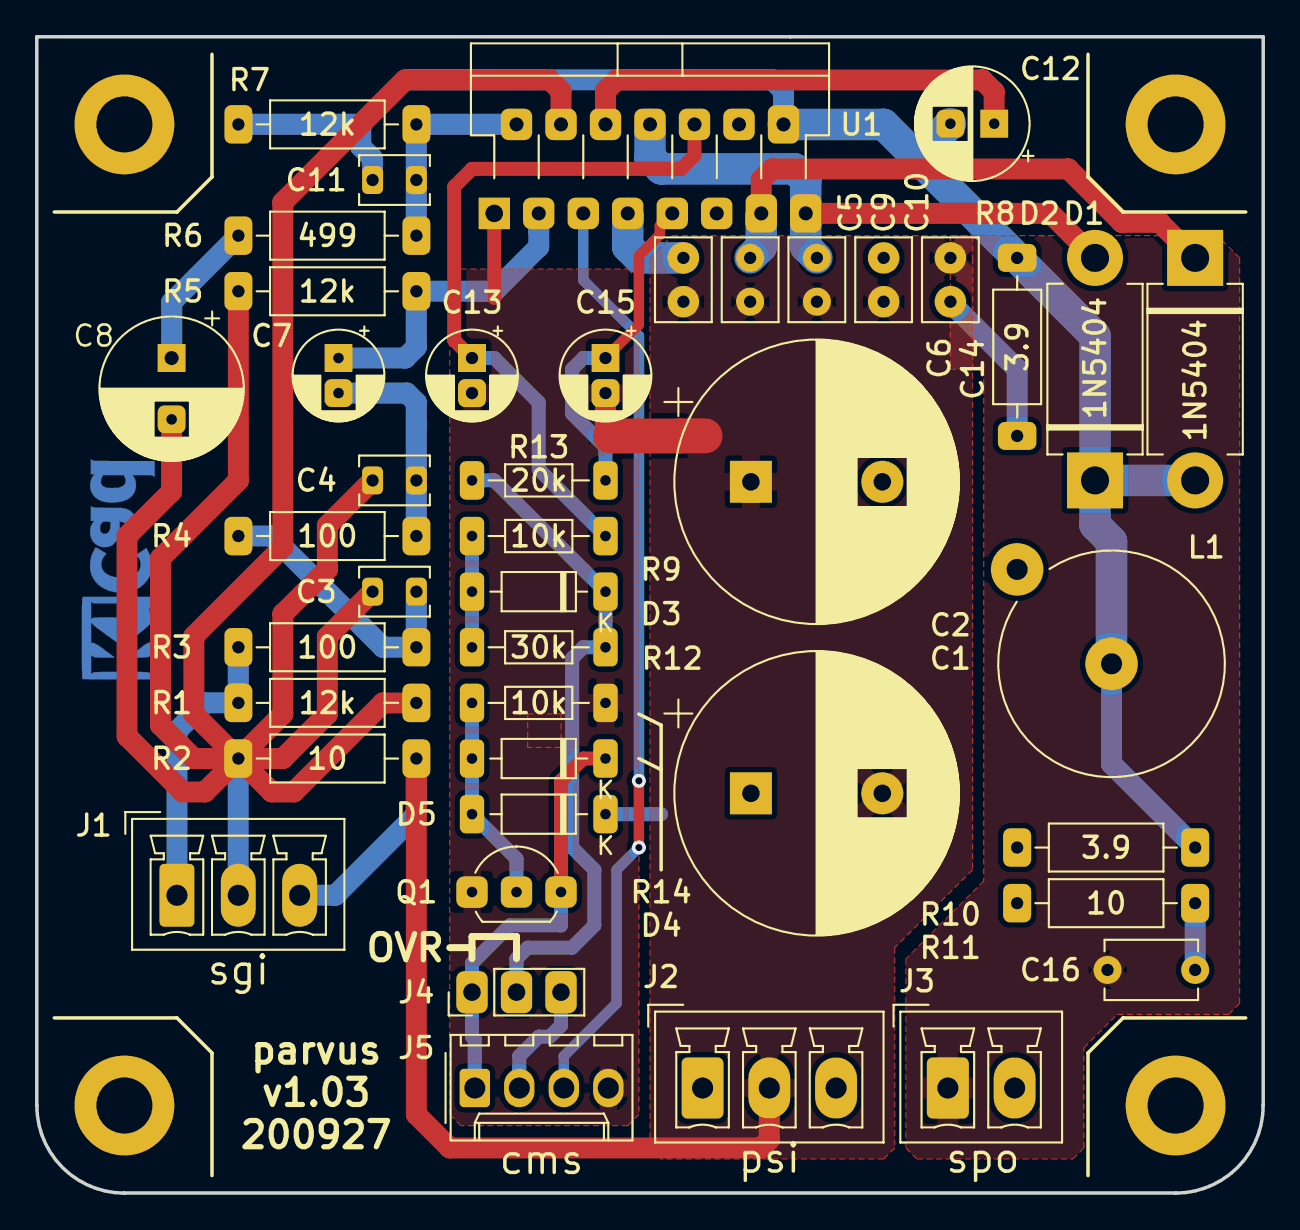
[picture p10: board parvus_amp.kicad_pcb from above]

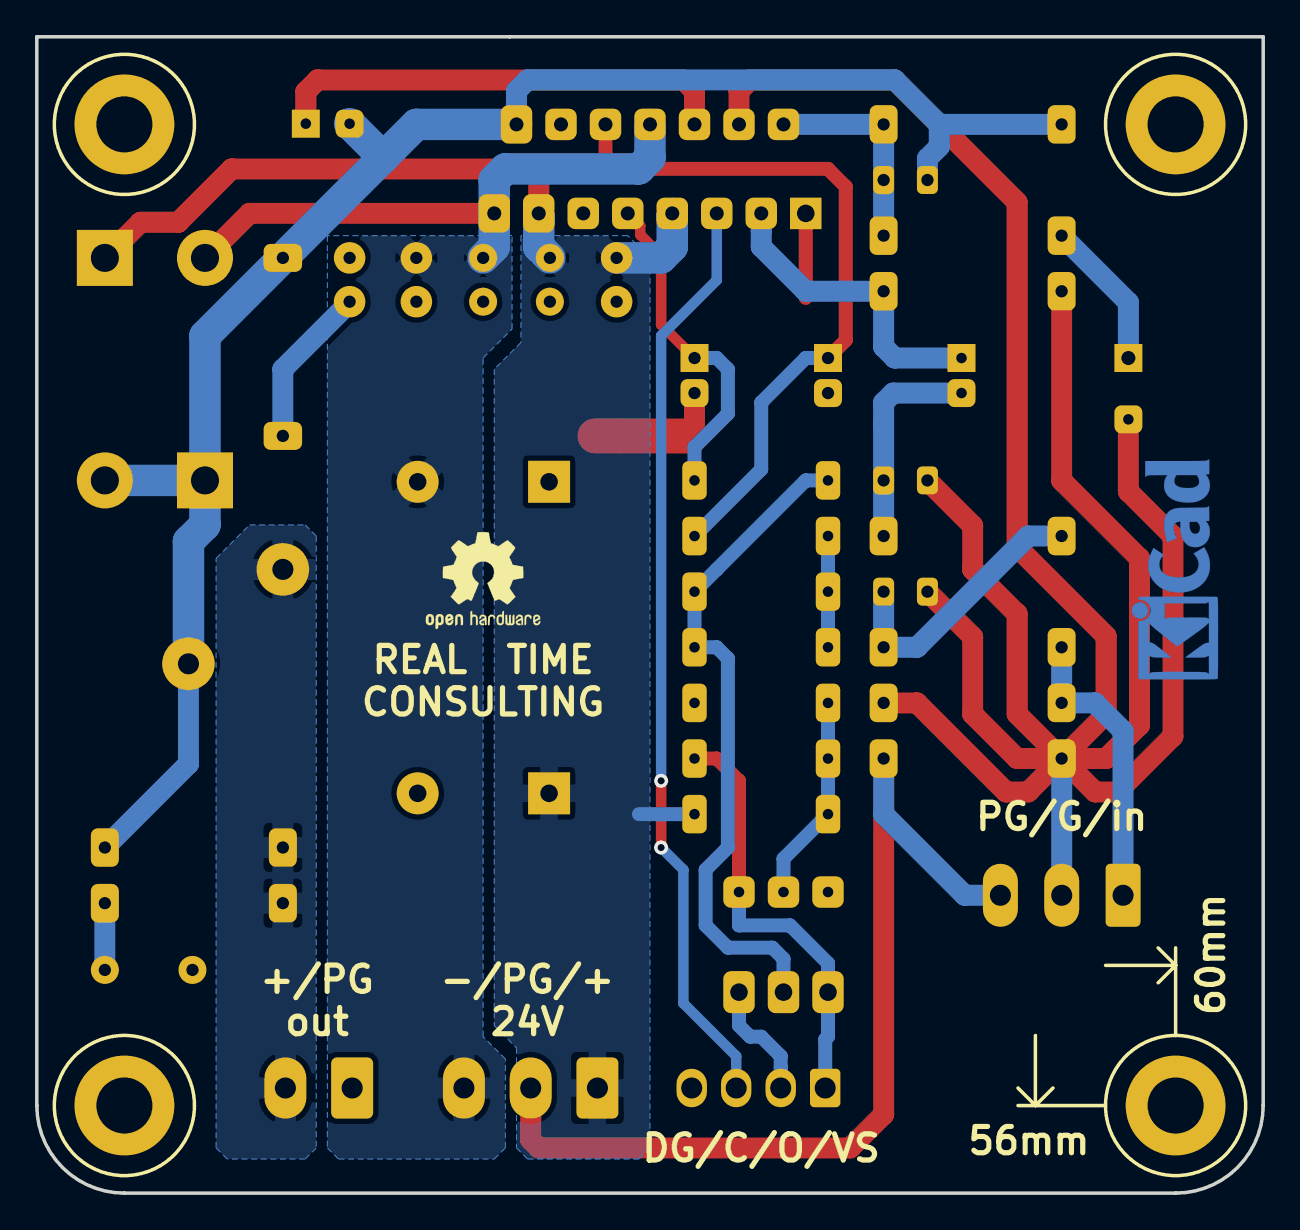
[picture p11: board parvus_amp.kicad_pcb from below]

Board: 2 copper layers, 70.0 x 66.0 mm, 50 parts (2 on the bottom side), 24 nets.

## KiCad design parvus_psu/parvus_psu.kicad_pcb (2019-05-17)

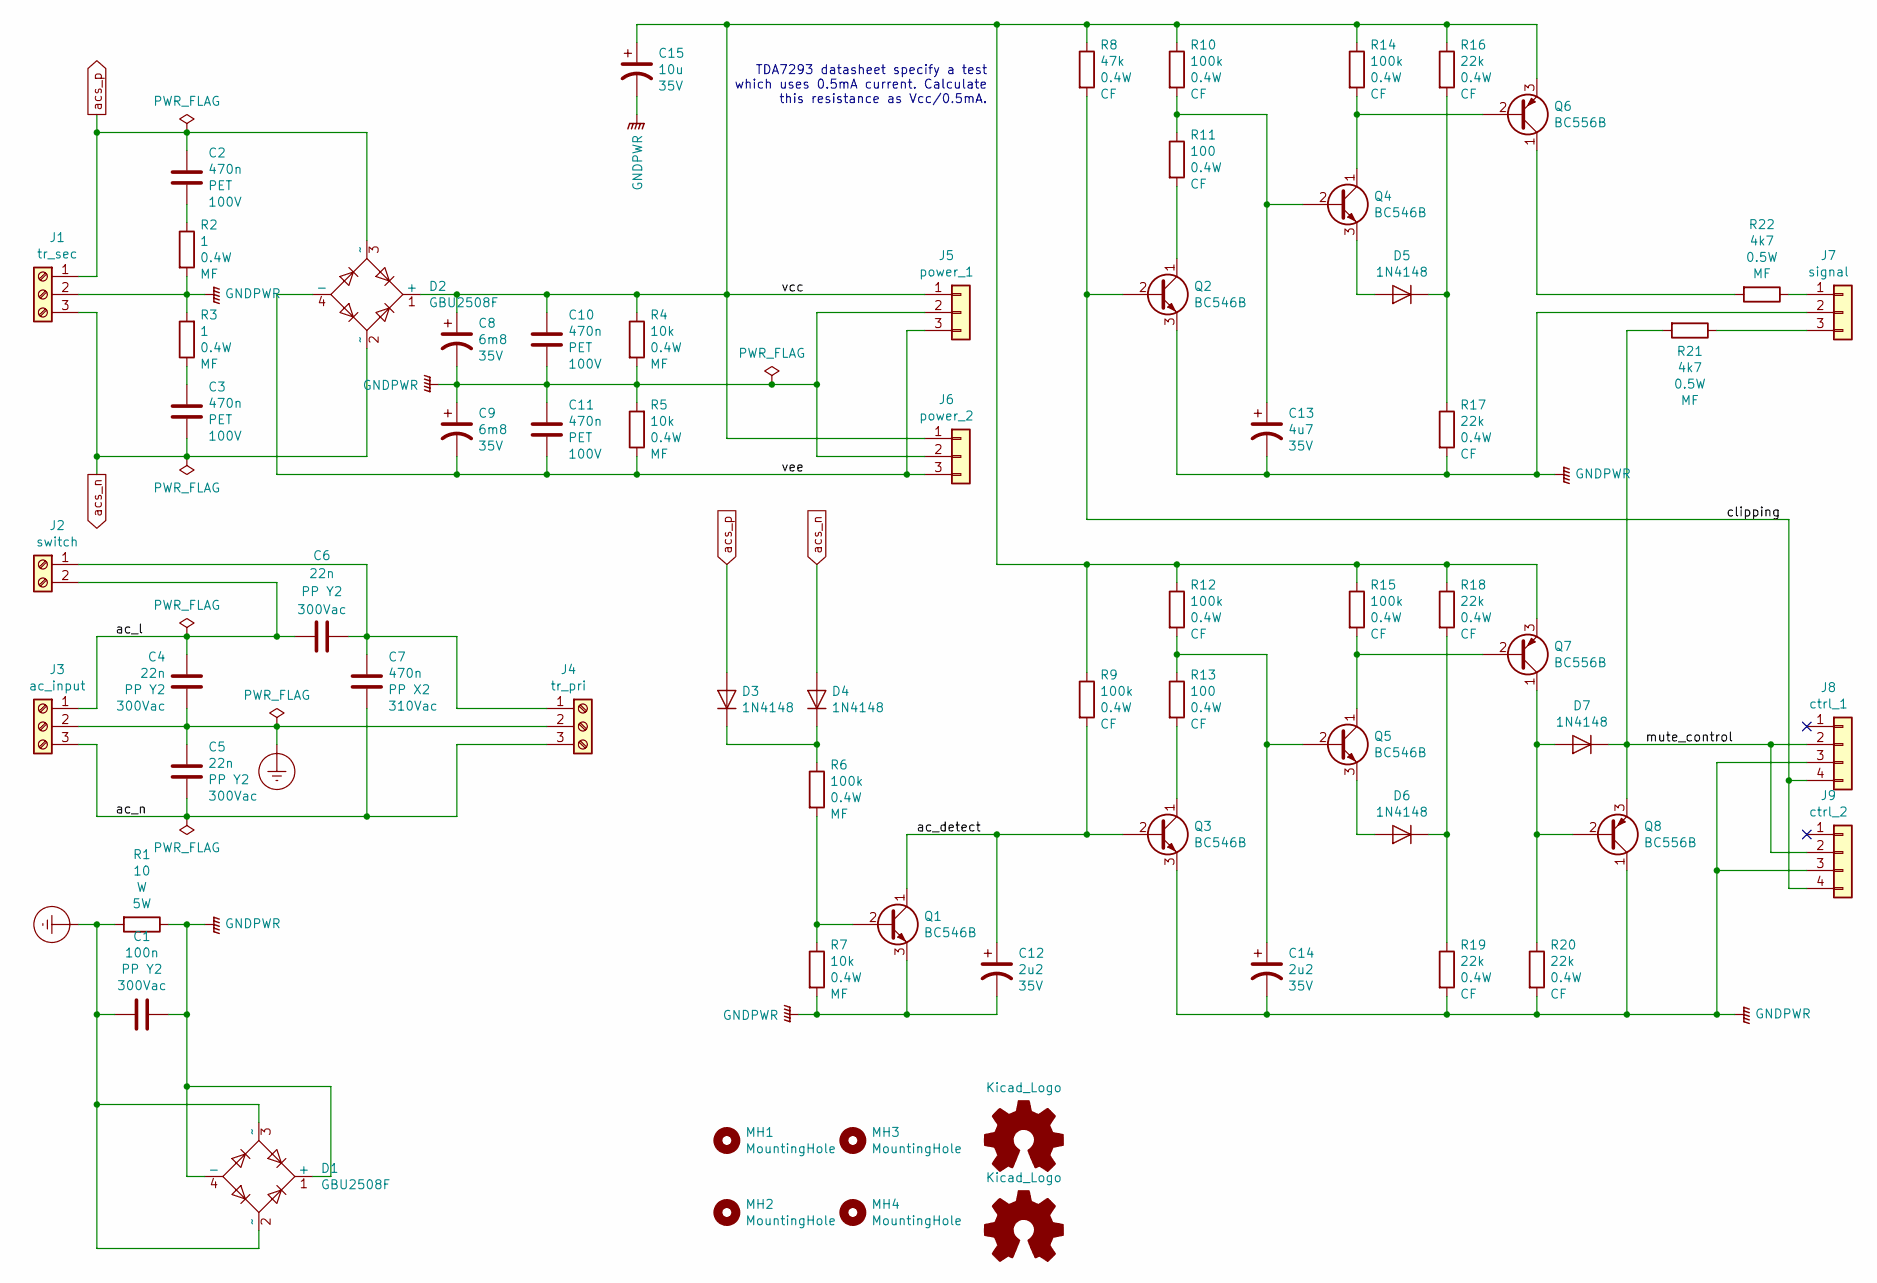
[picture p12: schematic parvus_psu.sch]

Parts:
C1: 100n; C_Rect_L26.5mm_W10.5mm_P22.50mm_MKS4; Voltage 300Vac
C2, C3, C10, C11: 470n; C_Rect_L7.2mm_W8.5mm_P5.00mm_FKP2_FKP2_MKS2_MKP2; Voltage 100V
C4, C5, C6: 22n; C_Rect_L18.0mm_W7.0mm_P15.00mm_FKS3_FKP3; Voltage 300Vac
C7: 470n; C_Rect_L18.0mm_W11.0mm_P15.00mm_FKS3_FKP3; Voltage 310Vac
C8, C9: 6m8; CP_Radial_D26.0mm_P10.00mm_SnapIn; Voltage 35V
C12, C14: 2u2; CP_Radial_D5.0mm_P2.50mm; Voltage 35V
C13: 4u7; CP_Radial_D5.0mm_P2.50mm; Voltage 35V
C15: 10u; CP_Radial_D8.0mm_P2.50mm; Voltage 35V
D1, D2: GBU2508F; Diode_Bridge_Vishay_GBU
D3, D4, D5, D6, D7: 1N4148; D_DO-35_SOD27_P7.62mm_Horizontal
J1: tr_sec; TerminalBlock_Phoenix_MKDS-3-3-5.08_1x03_P5.08mm_Horizontal
J2: switch; TerminalBlock_Phoenix_MKDS-3-2-5.08_1x02_P5.08mm_Horizontal
J3: ac_input; TerminalBlock_Phoenix_MKDS-3-3-5.08_1x03_P5.08mm_Horizontal
J4: tr_pri; TerminalBlock_Phoenix_MKDS-3-3-5.08_1x03_P5.08mm_Horizontal
J5: power_1; PhoenixContact_MCV_1,5_3-G-3.81_1x03_P3.81mm_Vertical
J6: power_2; PhoenixContact_MCV_1,5_3-G-3.81_1x03_P3.81mm_Vertical
J7: signal; PinHeader_1x03_P2.54mm_Vertical
J8: ctrl_1; PinHeader_1x04_P2.54mm_Vertical
J9: ctrl_2; PinHeader_1x04_P2.54mm_Vertical
LOGO1: Kicad_Logo; KiCad-Logo_5mm_Copper
LOGO2: Kicad_Logo; OSHW-Logo2_7.3x6mm_SilkScreen
MH1, MH2, MH3, MH4: MountingHole; MountingHole_3.2mm_M3_ISO7380_Pad
Q1, Q2, Q3, Q4, Q5: BC546B; TO-92_Inline_Wide
Q6, Q7, Q8: BC556B; TO-92_Inline_Wide
R1: 10; R_Axial_DIN0918_L18.0mm_D9.0mm_P22.86mm_Horizontal
R2, R3: 1; R_Axial_DIN0207_L6.3mm_D2.5mm_P10.16mm_Horizontal
R4, R5, R7: 10k; R_Axial_DIN0207_L6.3mm_D2.5mm_P10.16mm_Horizontal
R6, R9, R10, R12, R14, R15: 100k; R_Axial_DIN0207_L6.3mm_D2.5mm_P10.16mm_Horizontal
R8: 47k; R_Axial_DIN0207_L6.3mm_D2.5mm_P10.16mm_Horizontal
R11, R13: 100; R_Axial_DIN0207_L6.3mm_D2.5mm_P10.16mm_Horizontal
R16, R17, R18, R19, R20: 22k; R_Axial_DIN0207_L6.3mm_D2.5mm_P10.16mm_Horizontal
R21, R22: 4k7; R_Axial_DIN0309_L9.0mm_D3.2mm_P12.70mm_Horizontal

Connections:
/ac_detect: C12.1, Q1.1 (C), Q3.2 (B), R9.2
/ac_l: C4.1, C6.2, J2.2, J3.1
/ac_n: C5.2, C7.1, J3.3, J4.3
/clipping: J8.4, J9.4, Q2.2 (B), R8.2
/mute_control: D7.1 (K), J8.2, J9.2, Q8.3 (E), R21.2
/vcc: C8.1, C10.1, C15.1, D2.1 (+), J5.1, J6.1, Q6.3 (E), Q7.3 (E), R4.1, R8.1, R9.1, R10.1, R12.1, R14.1, R15.1, R16.1, R18.1
/vee: C9.2, C11.2, D2.4 (-), J5.3, J6.3, R5.1
Earth_Protective: C1.2, C4.2, C5.1, D1.2 (~~), D1.3 (~~), J3.2, J4.2, R1.2
GNDPWR: C1.1, C8.2, C9.1, C10.2, C11.1, C12.2, C13.2, C14.2, C15.2, D1.1 (+), D1.4 (-), J1.2, J5.2, J6.2, J7.2, J8.3, J9.3, Q1.3 (E), Q2.3 (E), Q3.3 (E), Q8.1 (C), R1.1, R2.2, R3.2, R4.2, R5.2, R7.2, R17.2, R19.2, R20.2
unnamed: C2.2, R2.1
unnamed: C3.1, R3.1
unnamed: C6.1, C7.2, J2.1, J4.1
unnamed: C13.1, Q4.2 (B), R10.2, R11.1
unnamed: C14.1, Q5.2 (B), R12.2, R13.1
unnamed: D3.1 (K), D4.1 (K), R6.1
unnamed: D5.1 (K), R16.2, R17.1
unnamed: D5.2 (A), Q4.3 (E)
unnamed: D6.1 (K), R18.2, R19.1
unnamed: D6.2 (A), Q5.3 (E)
unnamed: D7.2 (A), Q7.1 (C), Q8.2 (B), R20.1
unnamed: J7.1, R22.1
unnamed: J7.3, R21.1
unnamed: Q1.2 (B), R6.2, R7.1
unnamed: Q2.1 (C), R11.2
unnamed: Q3.1 (C), R13.2
unnamed: Q4.1 (C), Q6.2 (B), R14.2
unnamed: Q5.1 (C), Q7.2 (B), R15.2
unnamed: Q6.1 (C), R22.2
acs_n: C3.2, D2.2 (~~), D4.2 (A), J1.3
acs_p: C2.1, D2.3 (~~), D3.2 (A), J1.1

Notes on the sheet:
TDA7293 datasheet specify a test which uses 0.5mA current. Calculate this resistance as Vcc/0.5mA.

Board: 2 copper layers, 67 parts (0 on the bottom side), 30 nets, no tracks yet.

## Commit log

2018-08-03 Schematic finished
    [parvus_amp.kicad_pcb, parvus_amp.sch]
2019-01-08 Added a bunch of documentation.
    [parvus_amp.sch]
2019-01-22 Updated schematic and README description
    [parvus_amp.kicad_pcb, parvus_amp.sch]
2019-01-22 Using Phoenix MCV type of connectors
    [parvus_amp.kicad_pcb, parvus_amp.sch]
2019-01-31 Transition to TDA7293
    [parvus_amp.sch]
2019-02-01 WIP: Component placement.
    [parvus_amp.kicad_pcb, parvus_amp.sch]
2019-02-01 WIP: Routing components
    [parvus_amp.kicad_pcb, parvus_amp.sch]
2019-02-04 WIP: Component pad editing.
    [parvus_amp.kicad_pcb, parvus_amp.sch]
2019-02-05 Added text labels on silk screen.
    [parvus_amp.kicad_pcb]
2019-03-25 Added some Mouser identifiers
    [parvus_amp.sch]
2019-03-25 Added Mouser ID for AL capacitors.
    [parvus_amp.sch]
2019-03-25 Adjusted NFB capacitor footprint and rest of Mouser IDs.
    [parvus_amp.kicad_pcb, parvus_amp.sch]
2019-04-05 Minor tweaks to schematic and PCB.
    [parvus_amp.kicad_pcb, parvus_amp.sch]
2019-04-05 Added PSU project.
    [parvus_psu.kicad_pcb, parvus_psu.sch]
2019-04-23 Fixed the text regarding PCB organization.
2019-04-23 Corrected values for gain resistors.
2019-04-23 Added stubs for other section PCBs.
2019-05-10 Using 555 as AC detector.
    [parvus_psu.sch]
2019-05-16 Modified st-by/mute circuit values to accomodate control circuitry in PSU.
    [parvus_amp.sch]
2019-05-16 Finished schematic for AC detection circuit and clipping signaling.
    [parvus_psu.kicad_pcb, parvus_psu.sch]
2019-05-16 Added AC detection circuit simulation.
2019-05-17 Preliminary placement of AC detect and clipping circuitry.
    [parvus_psu.kicad_pcb, parvus_psu.sch]
2019-07-14 Moved bootstrap C4 away from PCB border near main heatsink.
    [parvus_amp.kicad_pcb]
2019-07-14 amp: Version bump to v1.01.
    [parvus_amp.kicad_pcb]
2019-08-23 Prerelease of version 1.02
    [parvus_amp.kicad_pcb, parvus_amp.sch]
2019-09-18 Updated to new version v1.02.
    [parvus_amp.kicad_pcb, parvus_amp.sch, parvus_psu.kicad_pcb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]
2019-09-18 Moved invisible f.silk text to f.fab layer.
    [parvus_amp.kicad_pcb]
2020-04-22 Project update
    [parvus_psu.kicad_pcb, parvus_psu.sch]
2020-09-27 Using consolidated modules, version bump to v1.03
    [parvus_amp.kicad_pcb, parvus_amp.sch]
2021-08-18 feat: updated obsolete components
    [parvus_amp.kicad_pcb, parvus_amp.ods]
2021-08-18 chore: project organization
    [parvus_amp.kicad_pcb]
